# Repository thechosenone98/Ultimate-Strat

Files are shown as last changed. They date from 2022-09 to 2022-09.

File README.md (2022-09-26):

# Ultimate Strat
This is a mod for a Fender Stratocaster guitar. It consist of 6x8 analog switch IC and allows to combine the 6 coils present inside 3 humbucker coils in any configuration you can imagine. To control it, you simply use a rotary encoder and the display tells you the current configuration you are in.

## Features
* Thousands of different combinations possible
* E-Ink Display makes the 9V battery last for a very long time (~1 year on the battery I used)
* Use your 5 way switch to change between 5 saved coil configurations
* You can save a profile (all 5 current configuration at once) by long pressing the rotary encoder for 4 seconds
* Shutdown by long pressing until screen flickers to a striped pattern
* Click the rotary encoder to wake up the system

## Usage
* Long press the rotary encoder for 3 seconds to enter the menu
* Click rotary encoder to select the coil you want to change
* Turn the rotary encoder to select the coil configuration
* Long press for 3 seconds to exit the menu

## PCB Design
<a href="https://github.com/thechosenone98/Ultimate-Strat/blob/master/ressources">
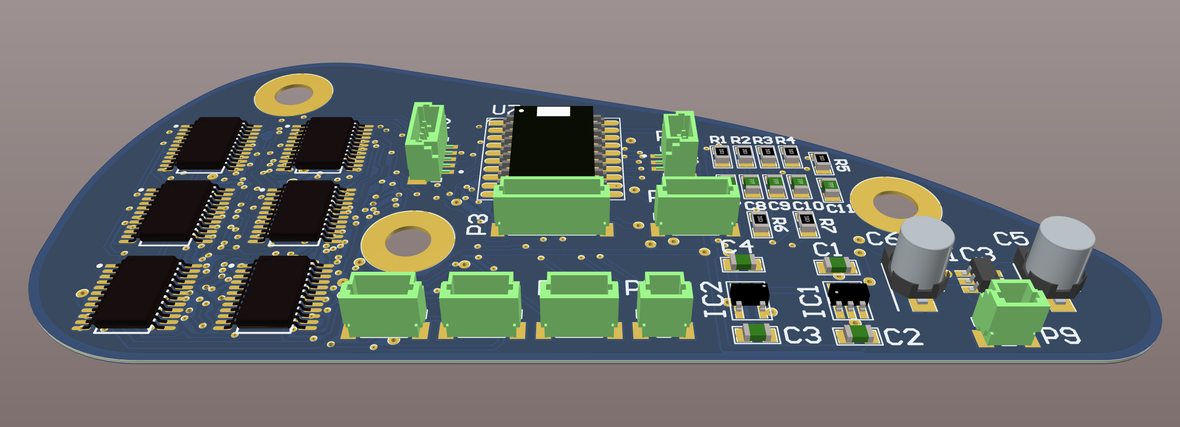
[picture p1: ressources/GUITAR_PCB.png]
PCB Design
</a>

## Demo Video

https://user-images.githubusercontent.com/13340366/190642919-1a8ae7ef-d05f-4ea6-937c-83752d77b2c1.mp4

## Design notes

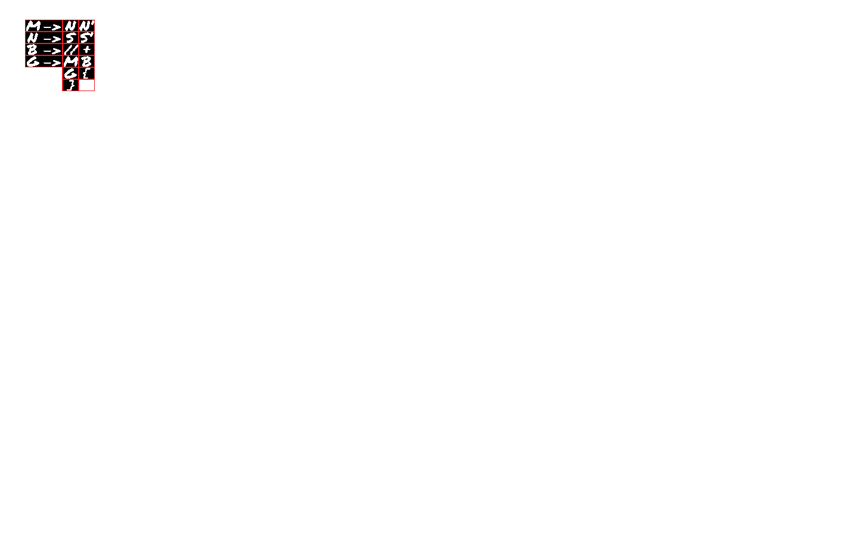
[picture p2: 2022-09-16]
Font/working.png

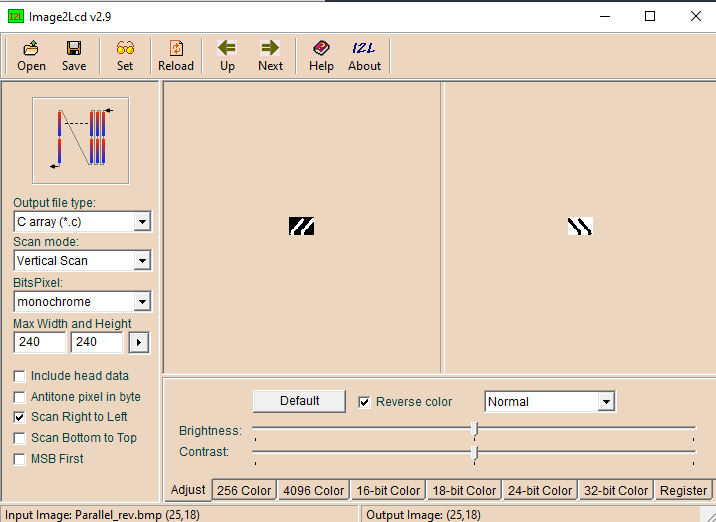
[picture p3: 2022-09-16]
Font/procédure exportation image.png

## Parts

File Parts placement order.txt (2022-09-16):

U1-U6 MAX395CAG+	
P2 CONN 5 PIN		
P3 CONN 8 PIN		
P4 CONN 3 PIN		
R1-R6 RES 10K		
C7-C12 CAP 0.1uF	
P1 CONN 5 PIN		
P6-P8 CONN 4 PIN	
P5 CONN 2 PIN		
IC2 MAX1726EUK50+T	
IC1 MAX1726EUK33+T	
C1-C4 CAP 1uF		
IC3 LM2664M6X		
P9 CONN 2 PIN		
C5-C6 CAP 3.3uF

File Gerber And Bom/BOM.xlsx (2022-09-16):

Comment | Description | Designator | Footprint | LibRef | Quantity
1uF | 1ÂµF Â±10% 25V Ceramic Capacitor X7R 0805 _2012 Metric_ | C1, C2, C3, C4 | 0805C-GENERIC | TMK212B7105KGHTR | 4
3.3uF | Capacitor Polarised | C5, C6 | CAPAE430X550N | 16SVP3R3M | 2
100nF | CAPACITOR 0805 CERAMIC | C7, C8, C9, C10, C11 | 0805C-TBD | 0805C-100nF-25V-X7R-MUR | 5
MAX1726EUK33+T | Integrated Circuit | IC1 | SOT23-5 | MAX1726EUK33+T | 1
MAX1726EUK50+T | Integrated Circuit | IC2 | SOT23-5 | MAX1726EUK50+T | 1
LM2664M6X_NOPB | Integrated Circuit | IC3 | SOT95P280X145-6N | LM2664M6X_NOPB | 1
PICKIT | Header, 5-Pin | P1 | JST_BM05B-SRSS-TB_LF_SN_0 | Header 5 | 1
ROTARY ENCODER | Header, 5-Pin | P2 | JST_BM05B-SRSS-TB_LF_SN_0 | Header 5 | 1
E-INK DISPLAY | Header, 8-Pin | P3 | JST_BM08B-SRSS-TB_LF_SN_0 | Header 8 | 1
5 WAY SWITCH | Header, 3-Pin | P4 | JST_BM03B-SRSS-TB_LF_SN_0 | Header 3 | 1
GUITAR OUTPUT JACK | Header, 2-Pin | P5 | JST_BM02B-SRSS-TB_LF_SN_0 | Header 2 | 1
Header 4 | Header, 4-Pin | P6, P7, P8 | JST_BM04B-SRSS-TB_LF_SN_0 | Header 4 | 3
9V CONNECTOR | Header, 2-Pin | P9 | JST_BM02B-SRSS-TB_LF_SN_0 | Header 2 | 1
10K | RESISTOR 0805 1/4 WATT THIN FILM | R1, R2, R3, R4, R5, R6, R7 | 0805R-10K | 0805R-10K | 7
MAX395CAG+ | No Description Available | U1, U2, U3, U4, U5, U6 | Maxim_Electronics_A24-2_IPC_C | MAX395CAG+ | 6
PIC16LF1769-I/SO | PIC PICÂ® XLPâ„¢ 16F Microcontroller IC 8-Bit 32MHz 14KB (8K x 14) FLASH 20-SOIC | U7 | SO20W | PIC16LF1769-I/SO | 1

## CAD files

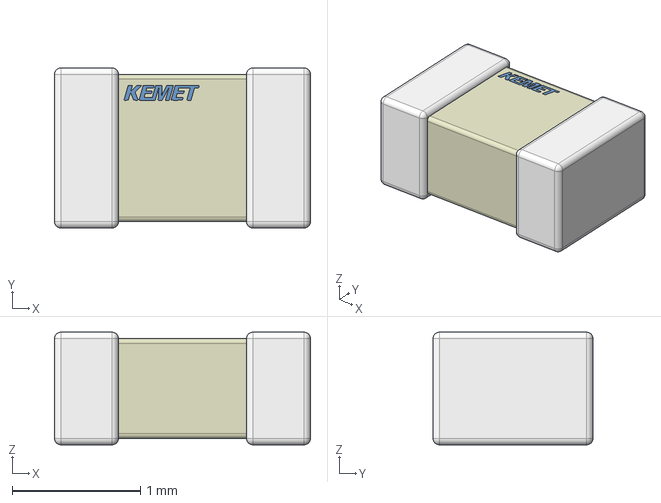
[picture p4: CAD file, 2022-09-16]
Parts Files/0.1uF SMD CAP/Cap_KEMET_C0805C104J8RACTU_eec.STEP
2.00 x 1.25 x 0.88 mm

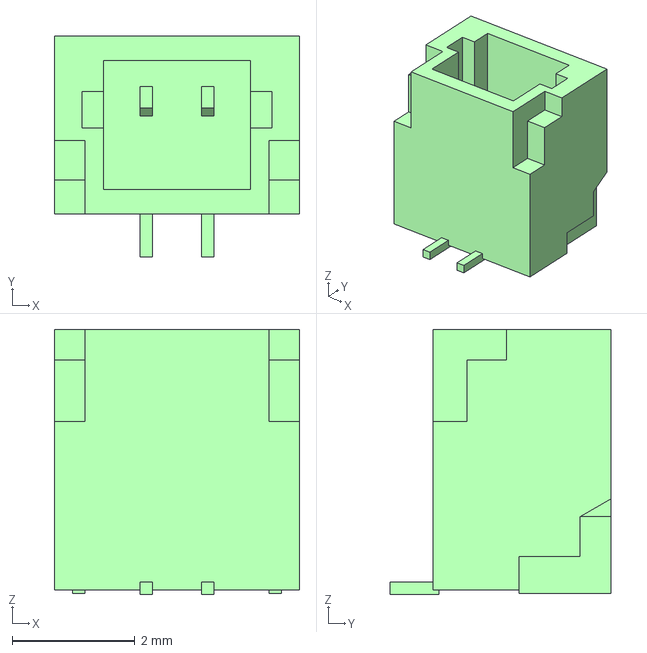
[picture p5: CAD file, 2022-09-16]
Parts Files/JST 2 PIN/Conn_JST_BM02B-SRSS-TB_LF_SN_eec.STEP
4.00 x 3.60 x 4.32 mm

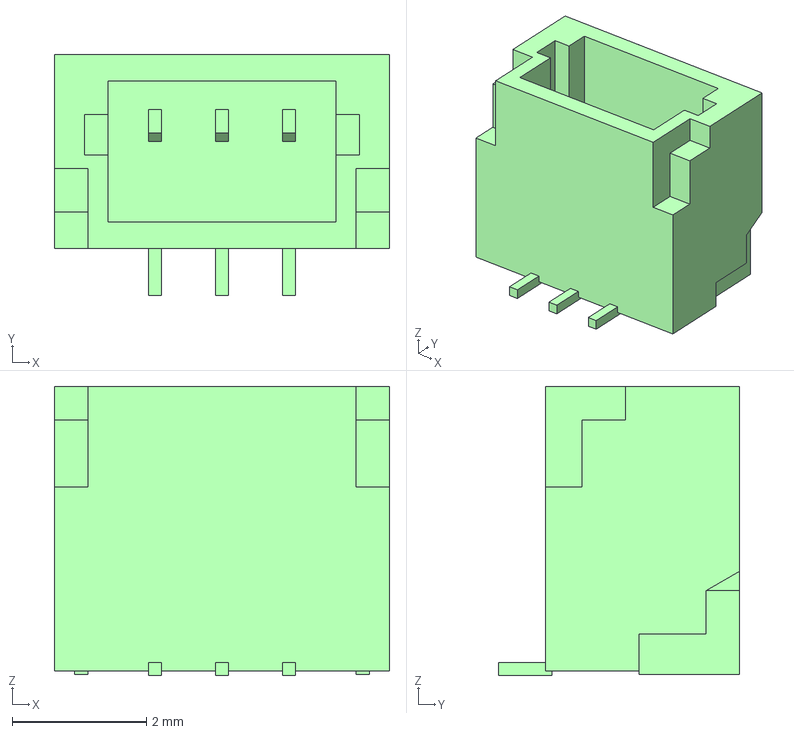
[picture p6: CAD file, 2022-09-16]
Parts Files/JST 3 PIN/Conn_JST_BM03B-SRSS-TB_LF_SN_eec.STEP
5.00 x 3.60 x 4.32 mm

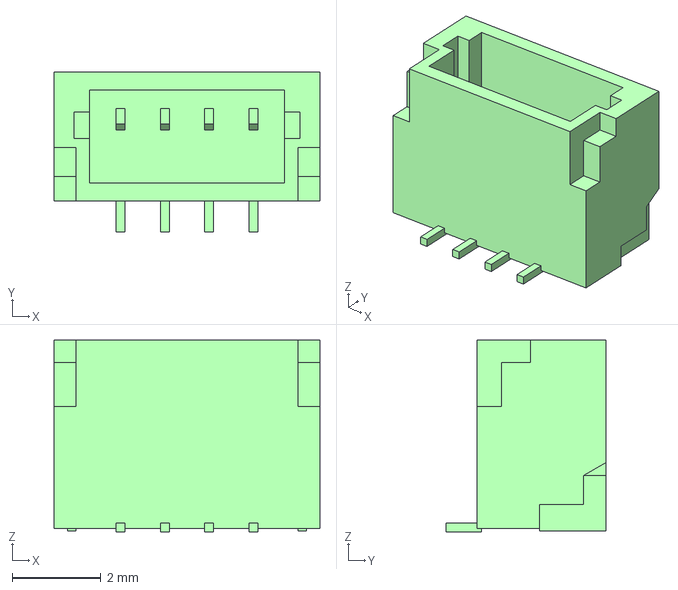
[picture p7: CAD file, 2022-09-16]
Parts Files/JST 4 PIN/Conn_JST_BM04B-SRSS-TB_LF_SN_eec.STEP
6.00 x 3.60 x 4.32 mm

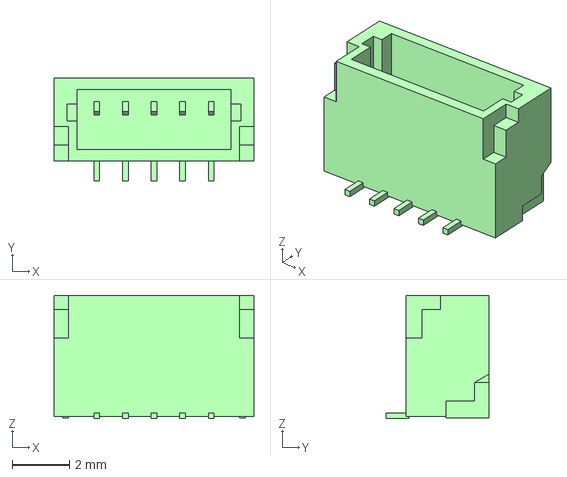
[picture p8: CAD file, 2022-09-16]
Parts Files/JST 5 PIN/Conn_JST_BM05B-SRSS-TB_LF_SN_eec.STEP
7.00 x 3.60 x 4.32 mm

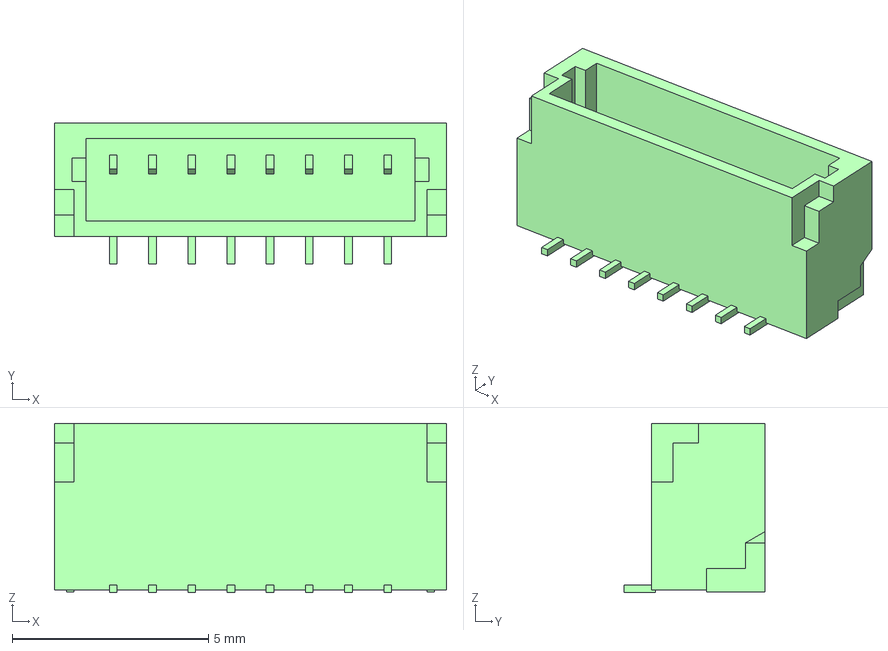
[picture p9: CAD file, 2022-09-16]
Parts Files/JST 8 PIN/Conn_JST_BM08B-SRSS-TB_LF_SN_eec.STEP
10.0 x 3.60 x 4.32 mm

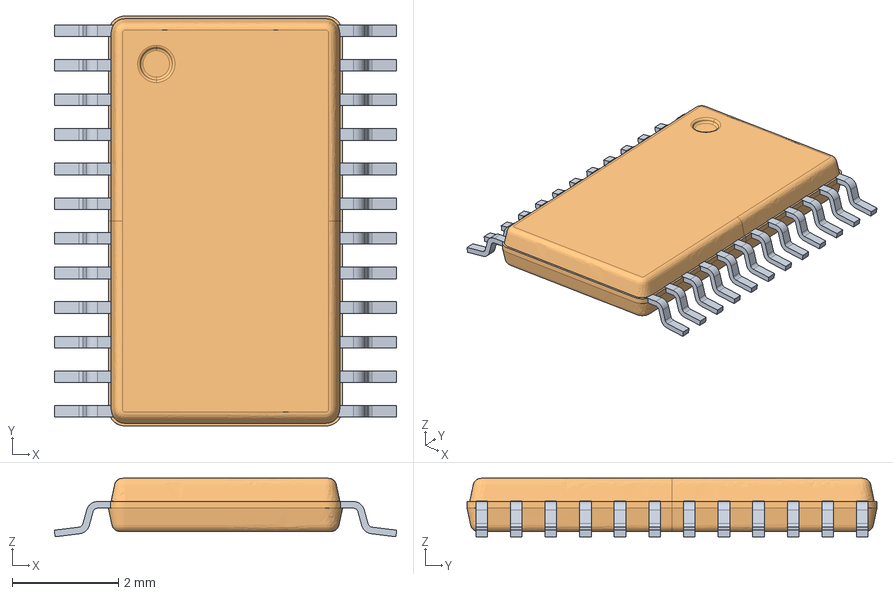
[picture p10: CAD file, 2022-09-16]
Parts Files/MAX395CAG+/IC_Maxim_Electronics_MAX395CAG+T_eec.STEP
6.43 x 7.70 x 1.10 mm

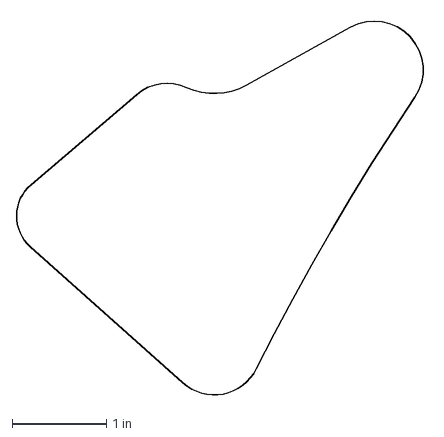
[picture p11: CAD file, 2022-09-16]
pcb_shape.dxf
4.36 x 4.04 in

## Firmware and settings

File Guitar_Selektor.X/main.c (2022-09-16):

/**
  Generated Main Source File

  Company:
    Microchip Technology Inc.

  File Name:
    main.c

  Summary:
    This is the main file generated using PIC10 / PIC12 / PIC16 / PIC18 MCUs

  Description:
    This header file provides implementations for driver APIs for all modules selected in the GUI.
    Generation Information :
        Product Revision  :  PIC10 / PIC12 / PIC16 / PIC18 MCUs - 1.81.7
        Device            :  PIC16LF1769
        Driver Version    :  2.00
*/

/*
    (c) 2018 Microchip Technology Inc. and its subsidiaries. 
    
    Subject to your compliance with these terms, you may use Microchip software and any 
    derivatives exclusively with Microchip products. It is your responsibility to comply with third party 
    license terms applicable to your use of third party software (including open source software) that 
    may accompany Microchip software.
    
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
    IN NO EVENT WILL MICROCHIP BE LIABLE FOR ANY INDIRECT, SPECIAL, PUNITIVE, 
    INCIDENTAL OR CONSEQUENTIAL LOSS, DAMAGE, COST OR EXPENSE OF ANY KIND 
    WHATSOEVER RELATED TO THE SOFTWARE, HOWEVER CAUSED, EVEN IF MICROCHIP 
    HAS BEEN ADVISED OF THE POSSIBILITY OR THE DAMAGES ARE FORESEEABLE. TO 
    THE FULLEST EXTENT ALLOWED BY LAW, MICROCHIP'S TOTAL LIABILITY ON ALL 
    CLAIMS IN ANY WAY RELATED TO THIS SOFTWARE WILL NOT EXCEED THE AMOUNT 
    OF FEES, IF ANY, THAT YOU HAVE PAID DIRECTLY TO MICROCHIP FOR THIS 
    SOFTWARE.
*/

#include "mcc_generated_files/mcc.h"
#include <stdint.h>
#include <stdbool.h>
#include "waveshare29epaper.h"
#include "guitar_image.h"
#include "guitar_regex.h"
#include "images.h"
#include "HEFlash.h"

#define LSBFIRST 0
#define MSBFIRST 1

const uint8_t configurations[] __at(0x1f80) = {0x01,0x00,0x00,0x00,0x01,0x01,0x00,0x0E,0x00,0x01,0x00,0x01,0x00,0x01,0x01,0x0F,0x00,0x00,0x01,0x02};

//Global variable used to keep the state we are in
PickupConfiguration saved_pc[5] = { {.neck=1, .middle=2, .bridge=3, .general=4},
                                    {.neck=5, .middle=10, .bridge=4, .general=2},
                                    {.neck=2, .middle=12, .bridge=13, .general=12},
                                    {.neck=1, .middle=15, .bridge=12, .general=21},
                                    {.neck=4, .middle=1, .bridge=5, .general=17}
                                    };

int8_t selection_index = -1;
uint8_t switch_pos = 0;
uint8_t prev_switch_pos = 0;
int8_t click_type = 0; //0 -> Nothing happened, 1-> Button Clicked, 2 -> Button pressed for 1 sec, 3 -> Button pressed for 3 sec
volatile int16_t click_timer = 0;
volatile bool button_clicked = false;
volatile bool time_to_refresh = true;
volatile uint16_t refresh_timer = 0;
uint64_t coil_conf;

void sendCoilsConfiguration(PickupConfiguration *pc);
void ButtonEventReset(void);

void ReadConfigurationsFromMemory(){
    HEFLASH_readBlock((void*)&saved_pc, 0, sizeof(saved_pc));
}

void WriteConfigurationToMemory(){
    HEFLASH_writeBlock(0, (void*)&saved_pc, sizeof(saved_pc));
}

bool sleeping = false;
bool wake_up = false;
void GotoSleep(void){
    InitDisplay(lut_full_update);
    ClearFrameMemory(0xA5);
    DisplayFrame();
    SleepDisplay();
    SHTDN_SetLow();
    COIL_RST_SetLow();
    DATA_CMD_SetLow();
    COIL_SEL_SetLow();
    EINK_SEL_SetLow();
    EINK_RST_SetLow();
    COIL_DATA_SetLow();
    COIL_CLK_SetLow();
    DELAY_milliseconds(2000);
    ButtonEventReset();
    sleeping = true;
    SLEEP();
}

void WakeUp(void){
    selection_index = -1;
    SHTDN_SetHigh();
    ButtonEventReset();
    TMR1_StartTimer();
    InitDisplay(lut_full_update);
    DELAY_milliseconds(1000);
    ClearFrameMemory(0xFF);
    DisplayFrame();
    ClearFrameMemory(0xFF);
    DisplayFrame();
    ReadConfigurationsFromMemory();
//    ImageFromPickupConf(&saved_pc[switch_pos], selection_index, false, false);
//    DisplayFrame();
//    ImageFromPickupConf(&saved_pc[switch_pos], selection_index, false, false);
//    DisplayFrame();
    InitDisplay(lut_partial_update);
    //TODO : Remove this and treat in while loop
    sendCoilsConfiguration(&saved_pc[switch_pos]);
}

int8_t modulo(int8_t x,int8_t N){
    return (x % N + N) % N;
}

void ButtonEventReset(void){
    click_type = 0;
    click_timer = 0;
    button_clicked = 0;
}

//Timer interrupt handler for the button events
void TMR1_CallBack()
{
    if(button_clicked) ++click_timer;
    if(switch_pos != prev_switch_pos){
        if(refresh_timer++ >= 1000) time_to_refresh = true;
    }
}

//Button interrupt handler (triggered when the button is pressed)
void Button_Callback(){
    if (PUSH_BTN_GetValue() == 0){
        if(sleeping){
            sleeping = false;
            wake_up = true;
        } else {
            button_clicked = true;
        }
    }
}

//Determines the type of button click the user inputed
void ButtonCaseHandler(void){
    //printf("%d\n", click_timer); //Prints the click timer value to UART
    if(button_clicked && click_type == 0){
        if(PUSH_BTN_GetValue() == 1){
            if(click_timer < 50) ButtonEventReset();
            else if(click_timer >= 50 && click_timer < 999) click_type = 1;
            else if(click_timer >= 1000 && click_timer < 2999) click_type = 2;
            else if(click_timer >= 3000) click_type = 3;
        }
        else if(click_timer >= 5000) click_type = 4;
    }
}

//Runs different routines based on the type of the button click
void ButtonEventHandler(void){
    switch(click_type){
        case 1:
            if(selection_index >= 0){ // Must be in select mode to use single click
                //printf("Button Clicked\n");
                //Remove the bracket from the previous line and copy the image on both buffer so it does not change when we refresh the next line
                ImageFromPickupConf(&saved_pc[switch_pos], selection_index, false, false);
                DisplayFrame();
                ImageFromPickupConf(&saved_pc[switch_pos], selection_index, false, false);
                DisplayFrame();
                selection_index = (selection_index + 1) % 4;
                ImageFromPickupConf(&saved_pc[switch_pos], selection_index, true, false);
                DisplayFrame();
                //printf("Mode : %c\n", selection_index == 0 ? 'N' : selection_index == 1 ? 'M' : selection_index == 2 ? 'B' : 'G');
            }
            break;
        case 2:
            //printf("Button clicked for 1 sec\n");
            selection_index = selection_index == -1 ? 0 : -1; //Toggle from idle mode to select mode
            if(selection_index == -1){
                ImageFromPickupConf(&saved_pc[switch_pos], selection_index, false, false);
                DisplayFrame();
                ImageFromPickupConf(&saved_pc[switch_pos], selection_index, false, false);
                DisplayFrame();
            } else {
                ImageFromPickupConf(&saved_pc[switch_pos], -1, false, true);
                DisplayFrame();
                ImageFromPickupConf(&saved_pc[switch_pos], -1, false, true);
                DisplayFrame();
                ImageFromPickupConf(&saved_pc[switch_pos], selection_index, true, false);
                DisplayFrame();
            }
            break;
        case 3:
            WriteConfigurationToMemory();
            break;
        case 4:
            //printf("Button Clicked for 3 sec\n");
            //Turn off everything
            GotoSleep();
            break;
        default:
            return;
    }
    ButtonEventReset(); //Reset the button click timer and type after the click has been handled
}

void SwitchEventHandler(void){
    //Convert gray code of switch to binary
    const uint8_t conv_table[6] = {0, 2, 1, 4, 0, 3};
    bool a1 = !A1_GetValue();
    bool a2 = !A2_GetValue();
    bool a3 = !A3_GetValue();
    //b3 is simply a3 so no point in creating a variable for it
    uint8_t new_switch_pos = conv_table[((a3 << 2) | (a2 << 1) | a1) - 1];
    if(new_switch_pos != switch_pos){
        switch_pos = new_switch_pos;
        sendCoilsConfiguration(&saved_pc[switch_pos]);
    }
}

void DisplayRefreshHandler(void){
    //Updates the display every second if need be (if the switch moved)
    //Allows fast response to switch for pickup configuration (having this runs every X ms instead
    //of every time switch changes position stops the image change from taking precedence over pickup configuration)
    if(time_to_refresh){
        prev_switch_pos = switch_pos;
        time_to_refresh = false;
        refresh_timer = 0;
        ImageFromPickupConf(&saved_pc[switch_pos], selection_index, true, false);
        DisplayFrame();
    }
}

int8_t read_rotary(void) {
    static int8_t rot_enc_table[] = {0,1,1,0,1,0,0,1,1,0,0,1,0,1,1,0};
    static uint8_t prevNextCode = 0;
    static uint16_t store=0;

    prevNextCode <<= 2;
    if (ROT_B_GetValue()) prevNextCode |= 0x02;
    if (ROT_A_GetValue()) prevNextCode |= 0x01;
    prevNextCode &= 0x0f;

    // If valid then store as 16 bit data.
    if  (rot_enc_table[prevNextCode] ) {
        store <<= 4;
        store |= prevNextCode;
        //if (store==0xd42b) return 1;
        //if (store==0xe817) return -1;
        if ((store&0xff)==0x2b) return -1;
        if ((store&0xff)==0x17) return 1;
    }
    return 0;
}

void RotaryEncoderEventHandler(void){
    static int8_t val;
    if(selection_index >= 0){ //If we are in select mode
        if((val = read_rotary())){
            switch(selection_index){
                case 0:
                    saved_pc[switch_pos].neck = modulo(saved_pc[switch_pos].neck + val, 17);
                    //printf("N : %s    %d\n", possible_pickup_conf_str[pc->neck], pc->neck);
                    break;
                case 1:
                    saved_pc[switch_pos].middle = modulo(saved_pc[switch_pos].middle + val, 17);
                    //printf("M : %s\n", possible_pickup_conf_str[pc->middle]);
                    break;
                case 2:
                    saved_pc[switch_pos].bridge = modulo(saved_pc[switch_pos].bridge + val, 17);
                    //printf("B : %s\n", possible_pickup_conf_str[pc->bridge]);
                    break;
                case 3:
                    saved_pc[switch_pos].general = modulo(saved_pc[switch_pos].general + val, 23);
                    //printf("G : %s\n", possible_general_conf_str[pc->general]);
                default:
                    break;
            }
            sendCoilsConfiguration(&saved_pc[switch_pos]);
            ImageFromPickupConf(&saved_pc[switch_pos], selection_index, true, false);
            DisplayFrame();
        }
    }
}

void shiftOut(uint8_t bitOrder, uint64_t val)
{
    uint64_t i;
    COIL_SEL_SetLow();
    for (i = 0; i < 48; i++)  {
        if (bitOrder == LSBFIRST)
            if (!!(val & ((uint64_t)1 << i)))
                COIL_DATA_SetHigh();
            else
                COIL_DATA_SetLow();
        else
            if (!!(val & ((uint64_t)1 << (47 - i))))
                COIL_DATA_SetHigh();
            else
                COIL_DATA_SetLow();

        COIL_CLK_SetHigh();
        COIL_CLK_SetLow();     
    }
    COIL_SEL_SetHigh();
}

void sendCoilsConfiguration(PickupConfiguration *pc){
    //Reset the coil_conf (we only OR on it so it would fill up otherwise)
    coil_conf = 0;
    //Start by filling 48 bit in the coil_conf to represent the 6x8 SPST ICs state
    coil_conf |= general_pickup_configuration_selectors[pc->general];
    coil_conf |= ((uint64_t)pickup_configuration_selectors[pc->bridge]) << 12;
    coil_conf |= ((uint64_t)pickup_configuration_selectors[pc->middle]) << 24;
    coil_conf |= ((uint64_t)pickup_configuration_selectors[pc->neck]) << 36;
    shiftOut(LSBFIRST, coil_conf);
}

/*
                         Main application
 */
int main(void)
{
    //Check for cause of RESET (if a reset occured)
    uint8_t reset_type = 0;
    if(STKOVF | STKUNF)
        reset_type = 1;
    else if(!PCONbits.nRI)
        reset_type = 2;
    else if((STATUS & 0x18) == 0x18 && (PCON & 0x0C) == 0x0C)
        reset_type = 3;
    // initialize the device
    SYSTEM_Initialize();
    //Pin setup
    INTERRUPT_GlobalInterruptEnable();
    INTERRUPT_PeripheralInterruptEnable();
    TMR1_SetInterruptHandler(TMR1_CallBack);
    IOCAF0_SetInterruptHandler(Button_Callback);
    if(!spi_master_open(EINK)){
		// Not able to open SPI, call fail() or optionally do something 
		// else waiting for the SPI to become free
		return 0;
    }
    
    WakeUp();
    
    if(reset_type == 1){
        STKOVF = 0;
        STKUNF = 0;
        PickupConfiguration stack_pc = {.neck=15, .middle=15, .bridge=15, .general=15};
        ImageFromPickupConf(&stack_pc, selection_index, true, false);
        DisplayFrame();
        DELAY_milliseconds(2000);
    }
    else if(reset_type == 2){
        PickupConfiguration reset_pc = {.neck=16, .middle=16, .bridge=16, .general=16};
        ImageFromPickupConf(&reset_pc, selection_index, true, false);
        DisplayFrame();
        DELAY_milliseconds(2000);
    }
    else if(reset_type == 3){
        PickupConfiguration reset_pc = {.neck=8, .middle=8, .bridge=8, .general=8};
        ImageFromPickupConf(&reset_pc, selection_index, true, false);
        DisplayFrame();
        DELAY_milliseconds(2000);
    }

    while (1)
    {
        if(wake_up){
            wake_up = false;
            WakeUp();
        }
        RotaryEncoderEventHandler();
        ButtonCaseHandler();
        ButtonEventHandler();
        SwitchEventHandler();
        DisplayRefreshHandler();
    }
}
/**
 End of File
*/

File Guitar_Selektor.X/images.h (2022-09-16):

/* 
 * File:   images.h
 * Author: zacfi
 *
 * Created on November 27, 2020, 10:58 PM
 */

#ifndef IMAGES_H
#define	IMAGES_H

//Rotated images
const unsigned char arrow_image_width_rot = 24;
const unsigned char arrow_image_height_rot = 61;
const unsigned char n_arrow_rot[183] = { /* 0X81,0X01,0X3D,0X00,0X12,0X00, */
0X00,0X00,0X00,0X00,0X00,0X00,0X00,0X18,0X00,0X00,0X38,0X00,0X00,0X3C,0X00,0X00,
0X7C,0X00,0X00,0X7C,0X00,0X00,0X7E,0X00,0X00,0XFE,0X00,0X00,0XFE,0X00,0X00,0XEF,
0X00,0X01,0XEF,0X00,0X01,0XC7,0X80,0X01,0XC7,0X80,0X01,0X83,0X80,0X00,0X03,0X80,
0X00,0X01,0X80,0X00,0X00,0X00,0X00,0X10,0X00,0X00,0X18,0X00,0X00,0X18,0X00,0X00,
0X18,0X00,0X00,0X18,0X00,0X00,0X18,0X00,0X00,0X18,0X00,0X00,0X18,0X00,0X00,0X18,
0X00,0X00,0X18,0X00,0X00,0X18,0X00,0X00,0X18,0X00,0X00,0X10,0X00,0X00,0X00,0X00,
0X00,0X00,0X00,0X00,0X00,0X00,0X00,0X00,0X00,0X00,0X00,0X00,0X00,0X00,0X00,0X00,
0X00,0X00,0X00,0X00,0X00,0X00,0X00,0X00,0X18,0X00,0X00,0X3F,0X00,0X00,0X7F,0XF0,
0X00,0X7F,0XFC,0X00,0X1F,0XFF,0X00,0X03,0XFF,0X80,0X00,0X3F,0X80,0X00,0X0F,0XC0,
0X1C,0X0F,0X80,0X3F,0XFF,0X00,0X7F,0XFE,0X00,0X7F,0XFC,0X00,0X7F,0XF8,0X00,0X0F,
0XFE,0X00,0X03,0XFF,0X80,0X00,0XFF,0XC0,0X00,0X3F,0XC0,0X00,0X0F,0X00,0X00,0X00,
0X00,0X00,0X00,0X00,0X00,0X00,0X00,};

const unsigned char m_arrow_rot[183] = { /* 0X81,0X01,0X3D,0X00,0X12,0X00, */
0X00,0X00,0X00,0X00,0X00,0X00,0X00,0X18,0X00,0X00,0X38,0X00,0X00,0X3C,0X00,0X00,
0X7C,0X00,0X00,0X7C,0X00,0X00,0X7E,0X00,0X00,0XFE,0X00,0X00,0XFE,0X00,0X00,0XEF,
0X00,0X01,0XEF,0X00,0X01,0XC7,0X80,0X01,0XC7,0X80,0X01,0X83,0X80,0X00,0X03,0X80,
0X00,0X01,0X80,0X00,0X00,0X00,0X00,0X10,0X00,0X00,0X18,0X00,0X00,0X18,0X00,0X00,
0X18,0X00,0X00,0X18,0X00,0X00,0X18,0X00,0X00,0X18,0X00,0X00,0X18,0X00,0X00,0X18,
0X00,0X00,0X18,0X00,0X00,0X18,0X00,0X00,0X18,0X00,0X00,0X10,0X00,0X00,0X00,0X00,
0X00,0X00,0X00,0X00,0X00,0X00,0X00,0X00,0X00,0X00,0X00,0X00,0X1F,0X00,0X00,0X3F,
0XFC,0X00,0X7F,0XFF,0X00,0X7F,0XFF,0X80,0X3F,0XFF,0XC0,0X1F,0XDF,0X80,0X0F,0XC0,
0X00,0X07,0XE0,0X00,0X03,0XF0,0X00,0X01,0XF0,0X00,0X01,0XF0,0X00,0X00,0XF0,0X00,
0X01,0XF0,0X00,0X1F,0XF0,0X00,0X3F,0XF0,0X00,0X7F,0XF0,0X00,0XFF,0XF0,0X00,0X7F,
0XE0,0X00,0X3F,0XF0,0X00,0X0F,0XFC,0X00,0X07,0XFF,0X00,0X00,0XFF,0XC0,0X00,0X3F,
0XC0,0X00,0X0F,0XC0,0X00,0X00,0X00,};

const unsigned char b_arrow_rot[183] = { /* 0X81,0X01,0X3D,0X00,0X12,0X00, */
0X00,0X00,0X00,0X00,0X00,0X00,0X00,0X18,0X00,0X00,0X38,0X00,0X00,0X3C,0X00,0X00,
0X7C,0X00,0X00,0X7C,0X00,0X00,0X7E,0X00,0X00,0XFE,0X00,0X00,0XFE,0X00,0X00,0XEF,
0X00,0X01,0XEF,0X00,0X01,0XC7,0X80,0X01,0XC7,0X80,0X01,0X83,0X80,0X00,0X03,0X80,
0X00,0X01,0X80,0X00,0X00,0X00,0X00,0X10,0X00,0X00,0X18,0X00,0X00,0X18,0X00,0X00,
0X18,0X00,0X00,0X18,0X00,0X00,0X18,0X00,0X00,0X18,0X00,0X00,0X18,0X00,0X00,0X18,
0X00,0X00,0X18,0X00,0X00,0X18,0X00,0X00,0X18,0X00,0X00,0X10,0X00,0X00,0X00,0X00,
0X00,0X00,0X00,0X00,0X00,0X00,0X00,0X00,0X00,0X00,0X00,0X00,0X00,0X00,0X00,0X00,
0X00,0X00,0X00,0X00,0X00,0X00,0X00,0X00,0X00,0X00,0X00,0X00,0X00,0X00,0X08,0X0E,
0X00,0X3E,0X1F,0X00,0X3F,0X3F,0X00,0X7F,0XFF,0X80,0X7F,0XEF,0X80,0XFF,0XE7,0XC0,
0XF3,0XE7,0XC0,0X73,0XF3,0XC0,0X79,0XF3,0XC0,0X7B,0XF1,0XC0,0X7F,0XFF,0XC0,0X7F,
0XFF,0XC0,0X7C,0XFF,0XC0,0X3E,0X0F,0XC0,0X3E,0X07,0X80,0X3C,0X00,0X00,0X18,0X00,
0X00,0X00,0X00,0X00,0X00,0X00,0X00,};

const unsigned char g_arrow_rot[183] = { /* 0X81,0X01,0X3D,0X00,0X12,0X00, */
0X00,0X00,0X00,0X00,0X00,0X00,0X00,0X18,0X00,0X00,0X38,0X00,0X00,0X3C,0X00,0X00,
0X7C,0X00,0X00,0X7C,0X00,0X00,0X7E,0X00,0X00,0XFE,0X00,0X00,0XFE,0X00,0X00,0XEF,
0X00,0X01,0XEF,0X00,0X01,0XC7,0X80,0X01,0XC7,0X80,0X01,0X83,0X80,0X00,0X03,0X80,
0X00,0X01,0X80,0X00,0X00,0X00,0X00,0X10,0X00,0X00,0X18,0X00,0X00,0X18,0X00,0X00,
0X18,0X00,0X00,0X18,0X00,0X00,0X18,0X00,0X00,0X18,0X00,0X00,0X18,0X00,0X00,0X18,
0X00,0X00,0X18,0X00,0X00,0X18,0X00,0X00,0X18,0X00,0X00,0X10,0X00,0X00,0X00,0X00,
0X00,0X00,0X00,0X00,0X00,0X00,0X00,0X00,0X00,0X00,0X00,0X00,0X00,0X00,0X00,0X00,
0X00,0X00,0X00,0X18,0X00,0X00,0X3C,0X00,0X00,0X3E,0X00,0X00,0X7E,0X00,0X00,0X7F,
0X00,0X38,0XFF,0X00,0X78,0XFF,0X00,0X7C,0XFF,0X80,0XFC,0X6F,0X80,0X7E,0X0F,0X80,
0X3E,0X07,0X80,0X3F,0X07,0XC0,0X1F,0X87,0XC0,0X1F,0XC7,0XC0,0X0F,0XC7,0XC0,0X07,
0XE7,0XC0,0X03,0XF7,0XC0,0X01,0XFF,0XC0,0X00,0XFF,0X80,0X00,0X7F,0X80,0X00,0X3E,
0X00,0X00,0X00,0X00,0X00,0X00,0X00,};

const unsigned char character_width_rot = 24;
const unsigned char character_height_rot = 25;
const unsigned char n_rot[75] = { /* 0X81,0X01,0X19,0X00,0X12,0X00, */
0X00,0X00,0X00,0X00,0X00,0X00,0X00,0X00,0X00,0X18,0X00,0X00,0X3E,0X00,0X00,0X7F,
0XF0,0X00,0X7F,0XFC,0X00,0X3F,0XFE,0X00,0X07,0XFF,0X80,0X00,0X3F,0X80,0X00,0X1F,
0XC0,0X08,0X0F,0X80,0X3F,0XFF,0X80,0X3F,0XFF,0X00,0X7F,0XFC,0X00,0X7F,0XF8,0X00,
0X1F,0XFC,0X00,0X07,0XFF,0X80,0X01,0XFF,0XC0,0X00,0X7F,0XC0,0X00,0X1F,0X80,0X00,
0X06,0X00,0X00,0X00,0X00,0X00,0X00,0X00,0X00,0X00,0X00,};

const unsigned char n_prime_rot[75] = { /* 0X81,0X01,0X19,0X00,0X12,0X00, */
0X78,0X00,0X00,0XFE,0X00,0X00,0XFF,0X00,0X00,0X3F,0X00,0X00,0X0E,0X00,0X00,0X00,
0X00,0X00,0X00,0X00,0X00,0X3E,0X00,0X00,0X7F,0XF0,0X00,0X7F,0XFC,0X00,0X7F,0XFE,
0X00,0X0F,0XFF,0X00,0X00,0X7F,0X80,0X00,0X1F,0XC0,0X08,0X0F,0X80,0X3F,0XFF,0X80,
0X3F,0XFF,0X00,0X7F,0XFC,0X00,0X7F,0XF8,0X00,0X1F,0XFC,0X00,0X07,0XFF,0X80,0X01,
0XFF,0XC0,0X00,0X7F,0XC0,0X00,0X1F,0X80,0X00,0X0E,0X00,};

const unsigned char s_rot[75] = { /* 0X81,0X01,0X19,0X00,0X12,0X00, */
0X00,0X00,0X00,0X00,0X00,0X00,0X00,0X00,0X00,0X18,0X00,0X00,0X38,0X00,0X00,0X78,
0X00,0X00,0X78,0X00,0X00,0XF8,0X00,0X00,0X78,0X3C,0X00,0X78,0X7E,0X00,0X78,0XFF,
0X00,0X79,0XEF,0X80,0X7D,0XEF,0X80,0X3F,0XC7,0XC0,0X3F,0XC7,0XC0,0X3F,0XC3,0XC0,
0X1F,0XC3,0XC0,0X1F,0XC3,0XC0,0X0F,0X83,0XC0,0X0F,0X80,0X00,0X00,0X00,0X00,0X00,
0X00,0X00,0X00,0X00,0X00,0X00,0X00,0X00,0X00,0X00,0X00,};

const unsigned char s_prime_rot[75] = { /* 0X81,0X01,0X19,0X00,0X12,0X00, */
0X00,0X00,0X00,0X60,0X00,0X00,0XF8,0X00,0X00,0XFE,0X00,0X00,0XFF,0X00,0X00,0X3F,
0X00,0X00,0X1E,0X00,0X00,0X38,0X00,0X00,0X78,0X00,0X00,0X78,0X00,0X00,0XF8,0X00,
0X00,0XF8,0X18,0X00,0X78,0X7E,0X00,0X78,0XFF,0X00,0X79,0XEF,0X00,0X7D,0XEF,0X80,
0X3F,0XC7,0X80,0X3F,0XC7,0XC0,0X3F,0XC3,0XC0,0X1F,0XC3,0XC0,0X1F,0XC3,0XC0,0X0F,
0X83,0XC0,0X0F,0X80,0X00,0X00,0X00,0X00,0X00,0X00,0X00,};

const unsigned char serie_rot[75] = { /* 0X81,0X01,0X19,0X00,0X12,0X00, */
0X00,0X00,0X00,0X00,0X00,0X00,0X00,0X00,0X00,0X00,0X00,0X00,0X00,0X00,0X00,0X00,
0X00,0X00,0X00,0X80,0X00,0X00,0XC0,0X00,0X00,0XC0,0X00,0X0D,0XC0,0X00,0X1F,0XC0,
0X00,0X1F,0XFC,0X00,0X0F,0XFE,0X00,0X03,0XFE,0X00,0X00,0XFC,0X00,0X00,0XC0,0X00,
0X00,0XC0,0X00,0X00,0XC0,0X00,0X00,0X00,0X00,0X00,0X00,0X00,0X00,0X00,0X00,0X00,
0X00,0X00,0X00,0X00,0X00,0X00,0X00,0X00,0X00,0X00,0X00,};
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

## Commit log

2022-09-16 Added project to GitHub
    [BOM.xlsx, Cap_KEMET_C0805C104J8RACTU_eec.STEP, Cap_KEMET_C0805C104J8RACTU_eec.SchLib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]
2022-09-16 Added ressource folder and README
    [BOM.xlsx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]
